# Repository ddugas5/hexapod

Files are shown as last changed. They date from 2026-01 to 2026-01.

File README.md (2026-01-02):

# Hexapod

YouTube Demo: (coming soon)
  
## Overview
This is a small hexapod robot that I am building as a personal project to gain experience as a robotics engineer. It has 18 degrees of freedom and is made from PLA 3D printed parts. I designed it in Solidworks and wrote the code for it on a Raspberry Pi 4B in ROS2/Python. As for the rest of my electronics, I made a custom servo driver and this was powered using a 7.4V 8000 mAh LiPo battery. I stepped this down to 5V using a DEVMO DC-DC Boot Buck Converter to power the Pi as well as the servos.

## Code
There are several ROS Nodes set up in this workspace. These are the core of what makes the hexapod move and how they all work together.
* servo_control_node
  * Subscribes to "/joint_angles" and then outputs a pwm to servo motors to put them to that angle
  * Also subscribes to "/servo/joint_5/cmd" to set the gripper to open or closed
* 

## Math

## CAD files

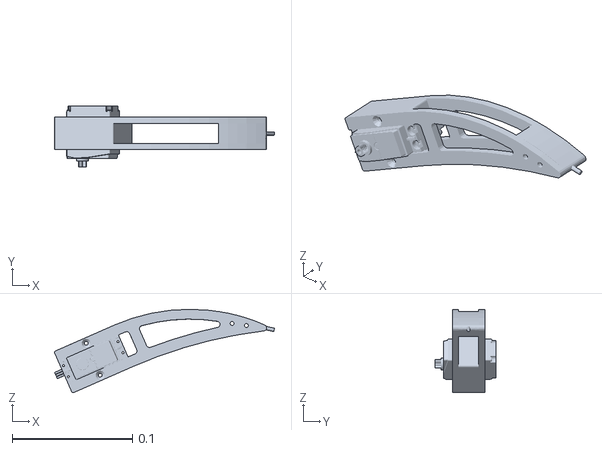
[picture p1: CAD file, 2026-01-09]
src/robot_description/meshes/middle_right_tibia_link.STL
0.183 x 0.0508 x 0.0693

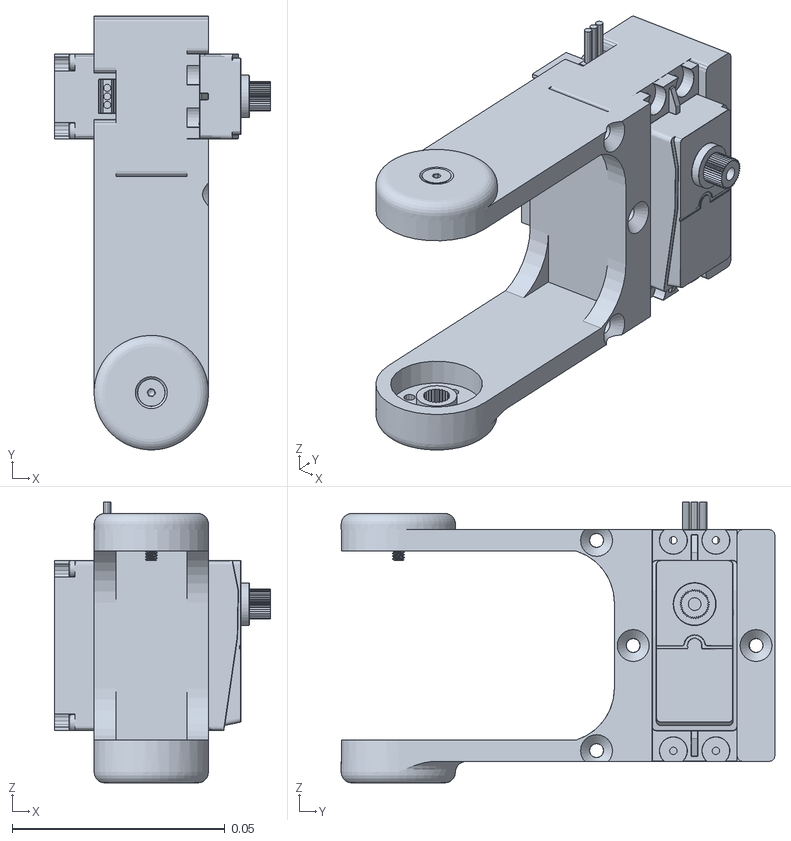
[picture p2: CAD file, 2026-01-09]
src/robot_description/meshes/middle_left_coxa_link.STL
0.0508 x 0.102 x 0.0661

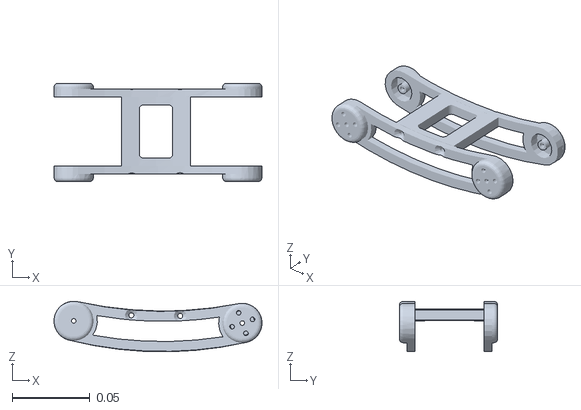
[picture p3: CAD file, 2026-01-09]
src/robot_description/meshes/front_left_femur_link.STL
0.134 x 0.0634 x 0.0325

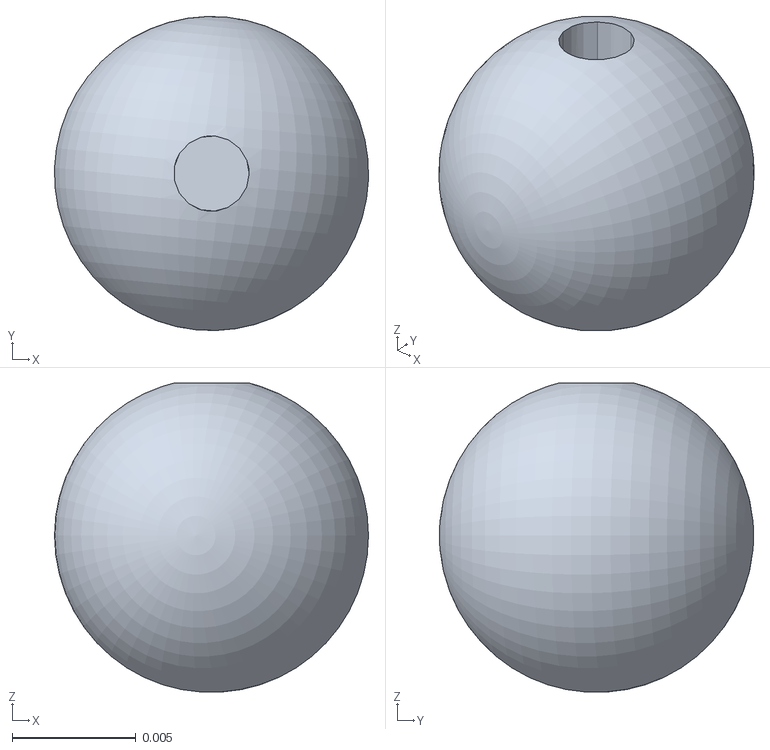
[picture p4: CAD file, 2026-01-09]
src/robot_description/meshes/front_left_foot_link.STL
0.0127 x 0.0127 x 0.0125

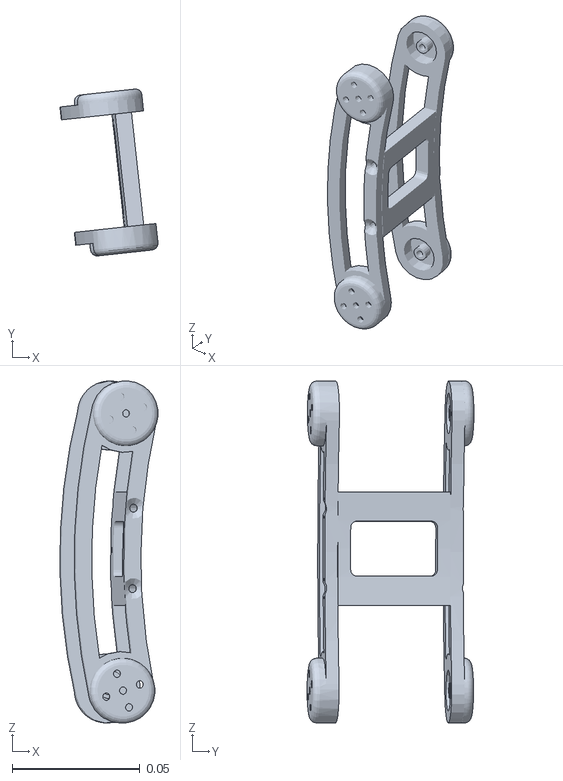
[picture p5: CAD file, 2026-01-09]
src/robot_description/meshes/middle_left_femur_link.STL
0.0384 x 0.0653 x 0.134

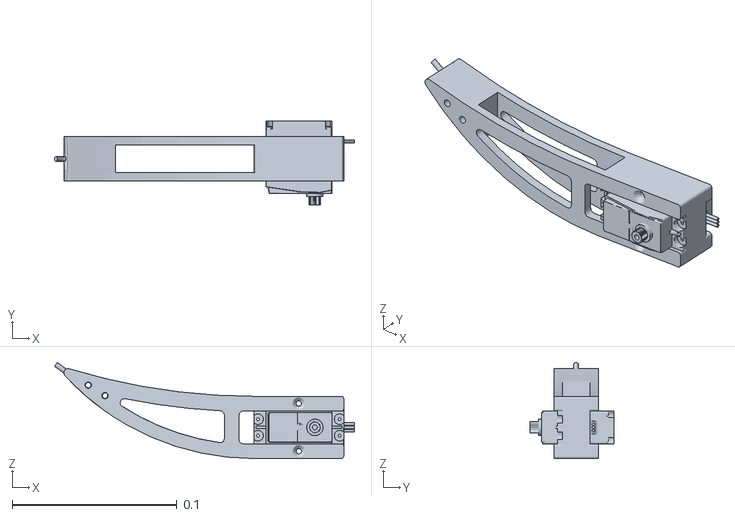
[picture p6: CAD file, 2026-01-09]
src/robot_description/meshes/front_left_tibia_link.STL
0.182 x 0.0508 x 0.0582

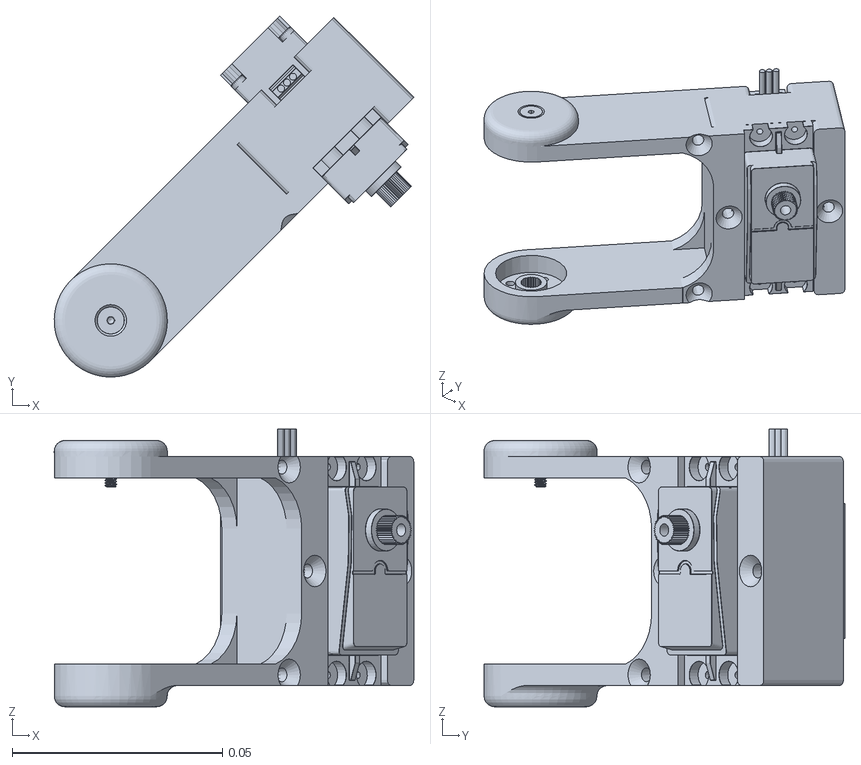
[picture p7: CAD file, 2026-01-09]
src/robot_description/meshes/front_left_coxa_link.STL
0.0855 x 0.0859 x 0.0661

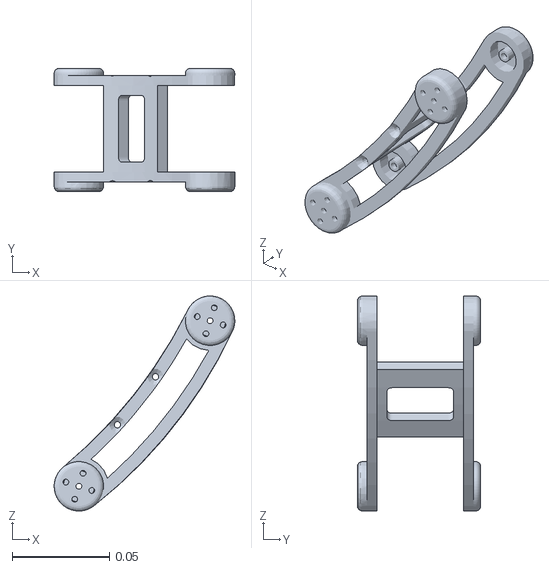
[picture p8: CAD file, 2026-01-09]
src/robot_description/meshes/middle_right_femur_link.STL
0.0928 x 0.0634 x 0.11

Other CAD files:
src/robot_description/meshes/middle_left_foot_link.STL
src/robot_description/meshes/middle_right_coxa_link.STL
src/robot_description/meshes/front_right_coxa_link.STL
src/robot_description/meshes/front_right_tibia_link.STL
src/robot_description/meshes/rear_right_tibia_link.STL
src/robot_description/meshes/middle_left_tibia_link.STL
src/robot_description/meshes/rear_left_tibia_link.STL
src/robot_description/meshes/front_right_foot_link.STL
src/robot_description/meshes/rear_right_foot_link.STL
src/robot_description/meshes/rear_left_coxa_link.STL
src/robot_description/meshes/front_right_femur_link.STL
src/robot_description/meshes/middle_right_foot_link.STL
src/robot_description/meshes/rear_left_femur_link.STL
src/robot_description/meshes/rear_left_foot_link.STL
src/robot_description/meshes/rear_right_coxa_link.STL
src/robot_description/meshes/rear_right_femur_link.STL

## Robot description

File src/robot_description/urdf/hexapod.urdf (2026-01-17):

<?xml version="1.0" encoding="utf-8"?>
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
<robot name="Hexapod">
  <link name="base_link">
    <inertial>
      <origin xyz="-6.18193581229152E-06 2.39717543056817E-06 0.0161961871063663" rpy="0 0 0" />
      <mass value="0.786295694888978" />
      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
    </inertial>
    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
  </link>
  <link name="front_left_coxa_link">
    <inertial>
      <origin xyz="0.042272 0.041896 0.00059547" rpy="0 0 0" />
      <mass value="0.086281" />
      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
    </inertial>
    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
  </link>
  <joint name="front_left_coxa_joint" type="revolute">
    <origin xyz="0.0597794623037307 0.0610074569827942 0.0154258000000004" rpy="0 0 0" />
    <parent link="base_link" />
    <child link="front_left_coxa_link" />
    <axis xyz="0.0425207281634428 0.00387756005096805 -0.999088060285229" />
    <limit lower="-1.57" upper="1.57" effort="0" velocity="0" />
  </joint>
  <link name="front_left_femur_link">
    <inertial>
      <origin xyz="0.052841 0.0010893 -0.0016863" rpy="0 0 0" />
      <mass value="0.0314" />
      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
    </inertial>
    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
  </link>
  <joint name="front_left_femur_joint" type="revolute">
    <origin xyz="0.0506354195835637 0.0493770568562628 0.0103729999999975" rpy="-0.000104123938980253 0.000104107183134694 0.785317693150283" />
    <parent link="front_left_coxa_link" />
    <child link="front_left_femur_link" />
    <axis xyz="0 1 0" />
    <limit lower="-1.57" upper="1.57" effort="0" velocity="0" />
  </joint>
  <link name="front_left_tibia_link">
    <inertial>
      <origin xyz="-0.036753 0.00043104 0.0037586" rpy="0 0 0" />
      <mass value="0.095402" />
      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
    </inertial>
    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
  </link>
  <joint name="front_left_tibia_joint" type="revolute">
    <origin xyz="0.108492266657861 0 -0.00133055426669743" rpy="0.000184555914276492 -0.000184623471871961 0.00026345026142038" />
    <parent link="front_left_femur_link" />
    <child link="front_left_tibia_link" />
    <axis xyz="0 -1 0" />
    <limit lower="0" upper="3.1415" effort="0" velocity="0" />
  </joint>
  <link name="front_left_foot_link">
    <inertial>
      <origin xyz="1.14070369122699E-09 -1.1370719643633E-10 -0.000139135605409638" rpy="0 0 0" />
      <mass value="0.00102687106652255" />
      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
    </inertial>
    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
  </link>
  <joint name="front_left_foot_joint" type="fixed">
    <origin xyz="-0.157028654923345 -0.000166190898608631 0.0381859537813213" rpy="-2.271181641943 -0.422454157208771 -1.23828061902425" />
    <parent link="front_left_tibia_link" />
    <child link="front_left_foot_link" />
    <axis xyz="0 0 0" />
  </joint>
  <link name="middle_left_coxa_link">
    <inertial>
      <origin xyz="-0.00060292 0.05847 0.00059547" rpy="0 0 0" />
      <mass value="0.086281" />
      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
    </inertial>
    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
  </link>
  <joint name="middle_left_coxa_joint" type="revolute">
    <origin xyz="0 0.0864545384187688 0.0154258000000007" rpy="0 0 0" />
    <parent link="base_link" />
    <child link="middle_left_coxa_link" />
    <axis xyz="-8.04594058439077E-05 -0.000183005707343813 -0.999999980017597" />
    <limit lower="-1.57" upper="1.57" effort="0" velocity="0" />
  </joint>
  <link name="middle_left_femur_link">
    <inertial>
      <origin xyz="-0.0051763 0.00052888 -0.052845" rpy="0 0 0" />
      <mass value="0.0314" />
      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
    </inertial>
    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
  </link>
  <joint name="middle_left_femur_joint" type="revolute">
    <origin xyz="2.10046607146265E-05 0.0696742115812287 0.0138198356843305" rpy="1.56394087721752 -1.46256545726282 0.00681533790492595" />
    <parent link="middle_left_coxa_link" />
    <child link="middle_left_femur_link" />
    <axis xyz="0 1 0" />
    <limit lower="-1.57" upper="1.57" effort="0" velocity="0" />
  </joint>
  <link name="middle_left_tibia_link">
    <inertial>
      <origin xyz="0.035157 0.00043104 0.011354" rpy="0 0 0" />
      <mass value="0.095402" />
      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
    </inertial>
    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
  </link>
  <joint name="middle_left_tibia_joint" type="revolute">
    <origin xyz="-0.00465888477440595 -0.000506201381017687 -0.108495899458512" rpy="0.000455617198050646 -1.15731885852398 0.107730800271824" />
    <parent link="middle_left_femur_link" />
    <child link="middle_left_tibia_link" />
    <axis xyz="0 -1 0" />
    <limit lower="0" upper="3.1415" effort="0" velocity="0" />
  </joint>
  <link name="middle_left_foot_link">
    <inertial>
      <origin xyz="8.33134791868419E-10 -7.87396869927903E-10 -0.000139135605393956" rpy="0 0 0" />
      <mass value="0.00102687106652256" />
      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
    </inertial>
    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
  </link>
  <joint name="middle_left_foot_joint" type="fixed">
    <origin xyz="0.15911554000758 -0.000166190898614748 0.0282561579362873" rpy="1.35669573662495 0 -1.57059641480066" />
    <parent link="middle_left_tibia_link" />
    <child link="middle_left_foot_link" />
    <axis xyz="0 0 0" />
  </joint>
  <link name="rear_left_coxa_link">
    <inertial>
      <origin xyz="-0.04032 0.043236 0.00059549" rpy="0 0 0" />
      <mass value="0.086281" />
      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
    </inertial>
    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
  </link>
  <joint name="rear_left_coxa_joint" type="revolute">
    <origin xyz="-0.0625828215626599 0.0588152120207696 0.0154258000000006" rpy="0 0 0" />
    <parent link="base_link" />
    <child link="rear_left_coxa_link" />
    <axis xyz="0 0 1" />
    <limit lower="-1.57" upper="1.57" effort="0" velocity="0" />
  </joint>
  <link name="rear_left_femur_link">
    <inertial>
      <origin xyz="0.053956 0.0016978 -0.0017331" rpy="0 0 0" />
      <mass value="0.030751" />
      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
    </inertial>
    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
  </link>
  <joint name="rear_left_femur_joint" type="revolute">
    <origin xyz="-0.0478016922764079 0.0515996698665222 0.0103730000000015" rpy="-0.00010412393892102 -0.000104140694076206 2.35611404162862" />
    <parent link="rear_left_coxa_link" />
    <child link="rear_left_femur_link" />
    <axis xyz="0 -1 0" />
    <limit lower="-1.57" upper="1.57" effort="0" velocity="0" />
  </joint>
  <link name="rear_left_tibia_link">
    <inertial>
      <origin xyz="-0.036754 0.00043104 0.0037527" rpy="0 0 0" />
      <mass value="0.095402" />
      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
    </inertial>
    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
  </link>
  <joint name="rear_left_tibia_joint" type="revolute">
    <origin xyz="0.108491987220254 0 -0.0013531475220351" rpy="0.000184610780237547 0.000184543218609282 0.000263479964488295" />
    <parent link="rear_left_femur_link" />
    <child link="rear_left_tibia_link" />
    <axis xyz="0 -1 0" />
    <limit lower="0" upper="3.1415" effort="0" velocity="0" />
  </joint>
  <link name="rear_left_foot_link">
    <inertial>
      <origin xyz="9.79572360726433E-10 -5.95212740206463E-10 -0.000139135605487437" rpy="0 0 0" />
      <mass value="0.00102687106652255" />
      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
    </inertial>
    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
  </link>
  <joint name="rear_left_foot_joint" type="fixed">
    <origin xyz="-0.157034797728908 -0.000166190898612381 0.0381606844208325" rpy="-2.1990344128274 -8.04446851697625E-05 -1.57097933897523" />
    <parent link="rear_left_tibia_link" />
    <child link="rear_left_foot_link" />
    <axis xyz="0 0 0" />
  </joint>
  <link name="front_right_coxa_link">
    <inertial>
      <origin xyz="0.04316 -0.041173 0.00059549" rpy="0 0 0" />
      <mass value="0.086281" />
      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
    </inertial>
    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
  </link>
  <joint name="front_right_coxa_joint" type="revolute">
    <origin xyz="0.0597479377257695 -0.0608728713812492 0.0154258000000012" rpy="0 0 0" />
    <parent link="base_link" />
    <child link="front_right_coxa_link" />
    <axis xyz="-0.0437385357924751 0.00789225955945658 0.999011838130949" />
    <limit lower="-1.57" upper="1.57" effort="0" velocity="0" />
  </joint>
  <link name="front_right_femur_link">
    <inertial>
      <origin xyz="0.053956 0.0016978 -0.0017331" rpy="0 0 0" />
      <mass value="0.030751" />
      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
    </inertial>
    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
  </link>
  <joint name="front_right_femur_joint" type="revolute">
    <origin xyz="0.0506416297387538 -0.0495369568805863 0.0103729999999976" rpy="-0.000104123938883876 -0.000104140694039058 -0.785478611961186" />
    <parent link="front_right_coxa_link" />
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

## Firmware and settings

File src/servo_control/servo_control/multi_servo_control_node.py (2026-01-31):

import rclpy
from rclpy.node import Node
from std_msgs.msg import Float32MultiArray
from adafruit_servokit import ServoKit

from adafruit_pca9685 import PCA9685
from adafruit_motor import servo

class MultiServoControlNode(Node):
    def __init__(self):
        super().__init__('multi_servo_control_node')
        self.subscription = self.create_subscription(
            Float32MultiArray,
            '/joint_angles',
            self.angle_callback,
            10
        )

        self.kit = ServoKit(channels=16)
    
        #store all channels, ranges, and whether to invert the servo or not
        self.servos = [
            {"channel": 0, "servo_min": 50, "servo_max": 120, "min_rad": -1.5708, "max_rad": 1.5708, "invert": False, "zero_offset_deg": 0.0}, #front_left_coxa
            {"channel": 1, "servo_min": 50, "servo_max": 180, "min_rad": -1.5708, "max_rad": 1.5708, "invert": True, "zero_offset_deg": 0.0}, #front_left_femur
            {"channel": 2, "servo_min": 0, "servo_max": 135, "min_rad": 0.0, "max_rad": 3.1415, "invert": True, "zero_offset_deg": 0.0},      #front_left_tibia
            {"channel": 3, "servo_min": 50, "servo_max": 120, "min_rad": -1.5708, "max_rad": 1.5708, "invert": False, "zero_offset_deg": 0.0},  # middle_left_coxa
            {"channel": 4, "servo_min": 50, "servo_max": 180, "min_rad": -1.5708, "max_rad": 1.5708, "invert": True, "zero_offset_deg": 0.0},   # middle_left_femur
            {"channel": 5, "servo_min": 0, "servo_max": 135, "min_rad": 0.0, "max_rad": 3.1415, "invert": True, "zero_offset_deg": 25.0},        # middle_left_tibia
            {"channel": 6, "servo_min": 50, "servo_max": 120, "min_rad": -1.5708, "max_rad": 1.5708, "invert": False, "zero_offset_deg": 0.0},       #rear_left_coxz
            {"channel": 7, "servo_min": 50, "servo_max": 180, "min_rad": -1.5708, "max_rad": 1.5708, "invert": True, "zero_offset_deg": 0.0},    #rear_left_femur
            {"channel": 8, "servo_min": 0, "servo_max": 135, "min_rad": 0.0, "max_rad": 3.1415, "invert": True, "zero_offset_deg": 0.0},     #rear_left_tibia
            {"channel": 9, "servo_min": 50, "servo_max": 120, "min_rad": -1.5708, "max_rad": 1.5708, "invert": False, "zero_offset_deg": 0.0},     #front_right_coxa
            {"channel": 10, "servo_min": 50, "servo_max": 180, "min_rad": -1.5708, "max_rad": 1.5708, "invert": True, "zero_offset_deg": 0.0},    #front_right_femur
            {"channel": 11, "servo_min": 0, "servo_max": 135, "min_rad": 0.0, "max_rad": 3.1415, "invert": True, "zero_offset_deg": 0.0},    #front_right_tibia
            {"channel": 12, "servo_min": 50, "servo_max": 120, "min_rad": -1.5708, "max_rad": 1.5708, "invert": True, "zero_offset_deg": 0.0},    #middle_right_coxa
            {"channel": 13, "servo_min": 50, "servo_max": 180, "min_rad": -1.5708, "max_rad": 1.5708, "invert": True, "zero_offset_deg": 0.0},    #middle_right_femur
            {"channel": 14, "servo_min": 0, "servo_max": 135, "min_rad": 0.0, "max_rad": 3.1415, "invert": True, "zero_offset_deg": 25.0},   #middle_right_tibia
            {"channel": 15, "servo_min": 50, "servo_max": 120, "min_rad": -1.5708, "max_rad": 1.5708, "invert": True, "zero_offset_deg": 0.0},    #rear_right_coxa
            {"channel": 16, "servo_min": 50, "servo_max": 180, "min_rad": -1.5708, "max_rad": 1.5708, "invert": True, "zero_offset_deg": 0.0},    #rear_right_femur
            {"channel": 17, "servo_min": 0, "servo_max": 135, "min_rad": 0.0, "max_rad": 3.1415, "invert": True, "zero_offset_deg": 0.0},    #rear_right_tibia
        ]

    def angle_callback(self, msg):
        # Only process middle left leg (indices 3, 4, 5)
        for i in range(3, 15):
            if i >= len(msg.data):
                break
            
            joint_angle = msg.data[i]
            configuration = self.servos[i]
        
        # # Original version - process all servos
        # for i, joint_angle in enumerate(msg.data):
        #     configuration = self.servos[i]

            #clamp radians
            joint_angle = max(configuration["min_rad"], min(configuration["max_rad"], joint_angle))

            #normalize to [0, 1]
            norm = (joint_angle - configuration["min_rad"]) / (
                configuration["max_rad"] - configuration["min_rad"]
            )
            
            #if the servo is inverted, change the sign
            if configuration["invert"]:
                norm = 1.0 - norm

            #convert to degrees (servo space)
            servo_angle = configuration["servo_min"] + norm * (configuration["servo_max"]
                        - configuration["servo_min"]) + configuration["zero_offset_deg"]
            
            #send to servo
            self.kit.servo[configuration["channel"]].angle = servo_angle

def main(args=None):
    rclpy.init(args=args)

    multi_servo_control_node = MultiServoControlNode()

    rclpy.spin(multi_servo_control_node)

    multi_servo_control_node.destoy_node()

    rclpy.shutdown()
    pca.sleep()

if __name__ == '__main__':
    main()

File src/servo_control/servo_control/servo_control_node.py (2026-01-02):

import rclpy
from rclpy.node import Node
from std_msgs.msg import Float32
from adafruit_servokit import ServoKit

from adafruit_pca9685 import PCA9685
from adafruit_motor import servo

class ServoControlNode(Node):
    def __init__(self):
        super().__init__('servo_control_node')
        self.subscription = self.create_subscription(
            Float32,
            '/servo_angle',
            self.angle_callback,
            10
        )

        #set the number of channels on the board
        self.kit = ServoKit(channels=16)

        #set the servo channel to the channel you want
        self.servo_channel = 0

    def angle_callback(self, msg: Float32):
        angle = msg.data    #get data and assign to variable

        self.kit.servo[self.servo_channel].angle = angle #attach the specified channel to the servo and the recieved angle to the servo

        self.get_logger().info(f'Set servo to angle {angle:.1f} degrees')

def main(args=None):
    rclpy.init(args=args)

    servo_control_node = ServoControlNode()

    rclpy.spin(servo_control_node)

    servo_control_node.destoy_node()

    rclpy.shutdown()

if __name__ == '__main__':
    main()

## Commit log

2026-01-02 recovering working files after corruption
    [front_left_coxa_link.STL, front_left_femur_link.STL, front_left_foot_link.STL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]
2026-01-05 writing initial inverse kinematics testing software
2026-01-05 Inverse kinematics math for femur and tibia are good in joint space. they seem to be off by a little but I need to test in motor space to be sure. right now i only have the math in joint space
2026-01-09 syncing urdfs across laptop and robot
    [hexapod.urdf]
2026-01-09 syncing urdf again
    [front_left_coxa_link.STL, front_left_femur_link.STL, front_left_foot_link.STL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]
2026-01-12 Basic inverse kinematics node is set up for calculating the angles for one leg. It also updates the joint states for all the joints of the hexapod so I can visualize it in the urdf. Next we will make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
2026-01-17 Inverse Kinematics are working with all of the legs and can be displayed in the URDF. The trajectory controller can send a multiarray of data and the legs can go to different points in space. Joint s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
    [hexapod.urdf]
2026-01-19 I have the beginning of putting the data in motor space and mapping them to their servos. Going to test it now
2026-01-22 changes to kinematics
2026-01-22 motor space for middle left joint looking a lot better. still might need some tweaks. i need to fix the mapping of the array being sent to joint space as well as the multi servo node
    [multi_servo_control_node.py, servo_control_node.py]
2026-01-24 changes to ik node and more additions to multi servo node
2026-01-24 added servo offsets to accomodate for servo error. this made foot placement match rviz better than before
    [multi_servo_control_node.py]
2026-01-26 Created a foot trajectory controller that controls one foot in a semicircle fashion. Needs to be tested on the hardware now as well as expanded to multiple legs and gait code
2026-01-26 Tested one leg walking gait on the hardware and it works great. It is a little slow but I am sure can be sped up
2026-01-31 First implementation of the tripod gait, it works in the urdf pretty well right now, about to try it on the actual robot
2026-01-31 Needed to flip the sign on the middle right servo and change the gait length to 3.0 inches. The code works well on the hardware. Right now I only have two legs working, need more legs and further gai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
    [multi_servo_control_node.py]
2026-02-08 Integrated PS4 Controller with the ROS2 Joy Node to control the movement of the robot. Now I need to add some more hardware and do some tweaking to get the leg movements in the right places. I also n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
2026-02-14 Successful test with joystick controller on the hardware. The foot trajectory controller had a bug that made the legs zip back to the starting position and now they have more fluid motion. Still need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
